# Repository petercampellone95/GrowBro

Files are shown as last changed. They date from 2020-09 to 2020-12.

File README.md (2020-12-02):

# GrowBro

Automated wireless plant growing solution BLE+WiFi(WIP)

To get started with development:

ESP32 IDF Setup (More complicated to build and setup, full functionality: https://docs.espressif.com/projects/esp-idf/en/latest/esp32/get-started/index.html

AND/OR

Arduino ESP32 Setup (Easier, limited functionality, one OS):
  1st: https://randomnerdtutorials.com/installing-the-esp32-board-in-arduino-ide-windows-instructions/
  2nd:https://www.youtube.com/watch?v=gm1N437ng1Y

INSTALL BOTH

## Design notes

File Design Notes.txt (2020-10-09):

PCB Design Notes 
Updated: 9/21/2020

ADC
	Internal ADC limited to 2600mV despite datasheet saying its capable of 3900mV
	Noisy, recommend 0.1uF per ADC input pin
	Might be better to use an external I2C/SPI ADC if higher precision reqd.

PCB Reqs
	Need BT in next rev (different ESP32-S2 PN)
	Smaller Vreg/Cheaper?
	Confirm holes sized for specific screw sizes
	Add 0.1uF on some ADC pins to test	
	Add I2C ports/headers

PCB Fixes
	C1/C5 ref des issue (fixed?)
	C1/C5 silkscreen off of vias
	Replace S1 with a switch that isnt dog shit
	CHIP_EN circuit needs pull-up and possible discharge circuit, reference datasheet
		https://www.espressif.com/sites/default/files/documentation/esp32-wrover_datasheet_en.pdf (page 20-21)
	Get rid of JTAG/USB headers
	Get slide switch for boot mode instead of jumper
	Actually order DC jack or get a smaller power input connector, rated max ~600-800mA
	External ADC, SPI/I2C, 8 CH
	Better noise mitigation strategies, lots of noise on ADC pins in current rev. 
	
PCB Assembly
	Options: Buy reflow oven $200-400
	Use EasyEDA: Have JLCPCB assemble

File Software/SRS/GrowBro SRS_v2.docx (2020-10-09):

# GrowBro

# Software Requirement Specification

1. Introduction
  1.1. The GrowBro ™ is an environment monitoring device that monitors the cultivation of plants. The goal of this system is to provide a reliable and scalable solution capable of supporting both home growers to grow centers. In addition to the main GrowBro ™, there will be a line of single-plant auxiliary wireless sensors that connect to the hub via Bluetooth LE.
2. Software Requirements
  2.1. GrowBro (Hub)
    2.1.1. WiFi Connectivity
      2.1.1.1. The software shall connect to the wireless network via IEEE 802.11 standard (WiFi).
      2.1.1.2. The software shall store the wireless network SSID and WPA key in a safe manor.
      2.1.1.3. The software shall try to automatically reconnect after a wireless network drop.
      2.1.1.4. The software shall transmit data to the external user interfaces via a WiFi connection.
      2.1.1.5. The software shall receive data from the external user interfaces via a WiFi connection.
    2.1.2. Bluetooth Connectivity
      2.1.2.1. The software shall be capable of transmitting data and commands to individual sensors via the Bluetooth LE protocol using the external user interface.
      2.1.2.2. The software shall be capable of receiving messages from the sensors periodically containing telemetry data, status info, and more via the Bluetooth LE protocol.
      2.1.2.3. The sensors will be paired with the GrowBro hub with a unique user specified ID prior to beginning standard operating procedure.
    2.1.3. Functionality
      2.1.3.1. The software shall receive Bluetooth messages from the sensors containing telemetry data, status info, and more every five minutes. The external user interface retains the ability to modify this report interval as desired.
      2.1.3.2. The software shall implement the ability to transmit Bluetooth messages from the GrowBro hub to individual sensors at the request of the user via the external software interfaces.
      2.1.3.3. Upon receipt of sensor data, the software shall push that data to the cloud.
  2.2. Wireless Temperature/Humidity
    2.2.1. Bluetooth Connectivity
      2.2.1.1. The software shall run an internal periodic script that takes temperature and humidity readings on a user specified interval. The user retains the ability to change this interval.
      2.2.1.2. The software shall relay back Bluetooth messages to the main hub that contains temperature and humidity data.
    2.2.2. Sensor Reading
      2.2.2.1. The software shall read the temperature from the sensor.
      2.2.2.2. The software shall read the humidity from the sensor.
  2.3. Wireless Moisture Sensor
    2.3.1. Bluetooth Connectivity
      2.3.1.1. The software shall run an internal periodic script that takes temperature and humidity readings on a user specified interval. The user retains the ability to change this interval.
      2.3.1.2. The software shall relay back Bluetooth messages to the main hub that contains moisture data.
    2.3.2. Sensor Reading
      2.3.2.1. The software shall read the moisture from the software.
  2.4. Phone Application
    2.4.1. Application Functionality
      2.4.1.1. The software shall gather information from the cloud.
      2.4.1.2. The software shall display information to the user.
    2.4.2. GUI
      2.4.2.1. Main Display
        2.4.2.1.1. The software shall display current temperature, humidity, and moisture sensor data as the main focal point.
      2.4.2.2. Tabbed Interface
        2.4.2.2.1. Settings
          2.4.2.2.1.1. The software shall allow the user to change the interface color.
        2.4.2.2.2. Connect/Disconnect
          2.4.2.2.2.1. The software shall add WiFi connection to the hub.
          2.4.2.2.2.2. The software shall change the Wifi connection to the hub.
          2.4.2.2.2.3. The software shall add a new Bluetooth device.
          2.4.2.2.2.4. The software shall remove a Bluetooth device.
          2.4.2.2.2.5. The software shall allow the user to specify a unique ID for each wireless Bluetooth sensor. A unique ID will be created if one is not provided by the user.
        2.4.2.2.3. Charts
          2.4.2.2.3.1. The software shall display 6 month, 1 month, 1 week, and 1 day options.
          2.4.2.2.3.2. Upon selection of options, must query the database on the cloud for the data and neatly print a line chart.
    2.4.3. WiFi Connectivity
      2.4.3.1. The software shall connect to a wireless network.
  2.5. Website Interface
    2.5.1. Application Functionality
      2.5.1.1. The software shall gather information from the cloud.
      2.5.1.2. The software shall display information to the user.
    2.5.2. GUI
      2.5.2.1. The software shall display current temperature, humidity, and moisture levels as the main focal point.

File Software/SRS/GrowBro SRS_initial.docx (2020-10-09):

# GrowBro

# Software Requirement Specification

1. Introduction
  1.1. The GrowBro ™ is an environment monitoring device that monitors the cultivation of plants. The goal of this system is to provide a reliable and scalable solution to cover the bases of home growers to grow centers. In addition to the main GrowBro ™, there will be a line of wireless sensors that connect to the hub via bluetooth.
2. Software Requirements
  2.1. GrowBro (Hub)
    2.1.1. WiFi Connectivity
      2.1.1.1. The software shall connect to the wireless network.
      2.1.1.2. The software shall try to automatically reconnect after a wireless network drop.
      2.1.1.3. The software shall send data to the external user interfaces.
    2.1.2. Bluetooth Connectivity
      2.1.2.1. The software shall send messages to the sensors containing commands for them to wake up and take a reading.
      2.1.2.2. The software shall receive messages from sensors containing sensor data.
    2.1.3. Functionality
      2.1.3.1. The software shall receive sensor data every five minutes.
      2.1.3.2. Upon receipt of sensor data, the software shall push that data to the cloud.
      2.1.3.3. The software shall send bluetooth messages to the sensors every five minutes.
  2.2. Wireless Temperature/Humidity
    2.2.1. Bluetooth Connectivity
      2.2.1.1. The software shall receive bluetooth messages from the main hub that contains information notifying the sensor to take a reading.
      2.2.1.2. The software shall send bluetooth messages to the main hub that contains temperature and humidity data in it.
    2.2.2. Sensor Reading
      2.2.2.1. The software shall read the temperature from the sensor.
      2.2.2.2. The software shall read the humidity from the sensor.
  2.3. Wireless Moisture Sensor
    2.3.1. Bluetooth Connectivity
      2.3.1.1. The software shall receive bluetooth messages from the main hub that contains information notifying the sensor to take a reading.
      2.3.1.2. The software shall send bluetooth messages to the main hub that contains temperature and humidity data in it.
  2.4. Phone Application
    2.4.1. Application Functionality
      2.4.1.1. The software shall gather information from the cloud.
      2.4.1.2. The software shall
    2.4.2. GUI
      2.4.2.1. Main Display
        2.4.2.1.1. The software shall display temperature, humidity, and moisture sensor data as the main focal point.
      2.4.2.2. Tabbed Interface
        2.4.2.2.1. Settings
        2.4.2.2.2. Connect/Disconnect
          2.4.2.2.2.1. The software shall add a new bluetooth device.
          2.4.2.2.2.2. The software shall remove a bluetooth device.
        2.4.2.2.3. Charts
          2.4.2.2.3.1. The software shall display 6 month, 1 month, 1 week, and 1 day options.
          2.4.2.2.3.2. Upon selection of options, must query the database on the cloud for the data and neatly print a line chart.
    2.4.3. WiFi Connectivity
  2.5. Website Interface
    2.5.1. Application Functionality
    2.5.2. GUI

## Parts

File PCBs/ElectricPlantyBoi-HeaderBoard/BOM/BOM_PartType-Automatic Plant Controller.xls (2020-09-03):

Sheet: BOM Report
Bill of Materials |  |  | <Parameter Title not found>
Source Data From: |  | Automatic Plant Controller.PrjPcb
Project: |  | Automatic Plant Controller.PrjPcb
Variant: |  | None
Creation Date: | 9/2/2020 | 10:57:59 PM
Print Date: | 2020-09-02 | 22:58:04
#Column Name Error:Footprint | Comment | #Column Name Error:LibRef | Designator | Description | Quantity
 | 1uF |  | C1 | 0805 1 uF 25 V ±10 % Tolerance X7R SMT Multilayer Ceramic Capacitor | 1
 | Adafruit 2223 Header |  | J1 | GPIO Stacking Header for Pi A+/B+/Pi 2/Pi 3 - Extra-long 2x20 Pins | 1
 | I2C |  | J2 | Board-To-Board Connector, Right Angle, WR-PHD Series, Through Hole, Header, 2, 2.54 mm | 1
 | SPI0 |  | J3 | Board-To-Board Connector, WR-PHD Series, Surface Mount, Header, 6, 2.54 mm, Gold Plated Contacts | 1
 | DHT-1 |  | J4 | THT Vertical Pin Header WR-PHD, Pitch 2.54 mm, Single Row, 3 pins | 1
 | DHT-2 |  | J5 | THT Vertical Pin Header WR-PHD, Pitch 2.54 mm, Single Row, 3 pins | 1
 | DHT-3 |  | J6 | THT Vertical Pin Header WR-PHD, Pitch 2.54 mm, Single Row, 3 pins | 1
 | DHT-4 |  | J7 | THT Vertical Pin Header WR-PHD, Pitch 2.54 mm, Single Row, 3 pins | 1
 | ADC0 |  | J8 | THT Vertical Pin Header WR-PHD, Pitch 2.54 mm, Single Row, 3 pins | 1
 | ADC4 |  | J9 | THT Vertical Pin Header WR-PHD, Pitch 2.54 mm, Single Row, 3 pins | 1
 | ADC1 |  | J10 | THT Vertical Pin Header WR-PHD, Pitch 2.54 mm, Single Row, 3 pins | 1
 | ADC5 |  | J11 | THT Vertical Pin Header WR-PHD, Pitch 2.54 mm, Single Row, 3 pins | 1
 | ADC2 |  | J12 | THT Vertical Pin Header WR-PHD, Pitch 2.54 mm, Single Row, 3 pins | 1
 | ADC6 |  | J13 | THT Vertical Pin Header WR-PHD, Pitch 2.54 mm, Single Row, 3 pins | 1
 | ADC3 |  | J14 | THT Vertical Pin Header WR-PHD, Pitch 2.54 mm, Single Row, 3 pins | 1
 | ADC7 |  | J15 | THT Vertical Pin Header WR-PHD, Pitch 2.54 mm, Single Row, 3 pins | 1
 | 10k |  | R1, R2 | Res, AEC-Q200, Thick Film, 10K, 5%, 0603 | 2
 | 4.7k |  | R3, R4, R5, R6 | Res Thin Film 0603 4.7K Ohm 1% 1/10W ±50ppm/°C Molded SMD SMD Paper T/R | 4
 | MCP3008T-I/SL |  | U1 | 2.7V 4-Channel/8-Channel 10-Bit A/D Converters with SPI Serial Interface, 16-Pin SOIC 150mil, Industrial Temperature, Tape and Reel | 1
 |  |  |  |  | 23
Approved |  | Notes

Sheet: Project Information
Project Full Path | C:\ProgramData\Altium\CircuitMaker {20690677-D4FD-4CB7-A4E9-00349D86A8F9}\Projects\354A3A29-DB29-4F35-BFF8-C48B12B8DA4F\e6ed39b2-680d-427f-b30a-50f9ef953f0c\Automatic Plant Controller.PrjPcb
Project Filename | Automatic Plant Controller.PrjPcb
Variant Name | None
Data-Source Filename | Automatic Plant Controller.PrjPcb
Data-Source Full Path | C:\ProgramData\Altium\CircuitMaker {20690677-D4FD-4CB7-A4E9-00349D86A8F9}\Projects\354A3A29-DB29-4F35-BFF8-C48B12B8DA4F\e6ed39b2-680d-427f-b30a-50f9ef953f0c\Automatic Plant Controller.PrjPcb
Title | <Parameter Title not found>
Total Quantity | 23
Report Time | 10:57:59 PM
Report Date | 9/2/2020
Report Date & Tine | 9/2/2020 10:57:59 PM
Output Name | BOM_PartType
Output Type | BOM_PartType
Output Generator Name | BOM
Output Generator Description | Bill of Materials

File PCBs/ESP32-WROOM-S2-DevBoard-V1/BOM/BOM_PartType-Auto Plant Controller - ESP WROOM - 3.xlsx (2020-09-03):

Comment | Description | Designator | Footprint | LibRef | Quantity | Capacitance | Manufacturer Part Number | PartType | Power Rating | Voltage Rating (DC)
0.1uF | 0402 0.1 uF 25 V ±10% Tolerance X5R SMT Multilayer Ceramic Capacitor | C1 | PCB-5bhg8adqnzhgtf4b63gj-1 | CMP-76b0bfb95be4a977-1 | 1 | 100 nF | TMK105BJ104KV-F | 0.1uF |  | 25.0 V
22uF | LMK212BJ226MG-T TAIYO YU DEN CERAMIC CAPACITOR 22U F 20% 10V X5R 0805 RoHS | C2 | C0805 | CMP-3afbf396deb1e53c-2 | 1 |  |  | 22uF |  | 10.0 V
0.1uF | 0402 0.1 uF 10 V ±10 % Tolerance X5R Surface Mount Multilayer Ceramic Capacitor | C3 | 0402C | CMP-19299680-6 | 1 | 100 nF | GRM155R61A104KA01D | 0.1uF |  | 10.0 V
10uF | CAP CER 10UF 10V 10% X5R 0805 | C4 | PCB-19299738-1 | CMP-19299738-2 | 1 | 1e-05 F | GRM21BR61A106KE19L | 10uF |  | 10.0 V
0.1uF | 0.1uF, ±10%, 50V, X7R, 0805, Multilayer Ceramic Capacitor | C5 | PCB-oygqt4xf3sesynjclq4r-1 | CMP-2758844-5 | 1 | 100 nF | CL21B104KBCNNNC | 0.1uF |  | 50.0 V
3V3_PWR | 1.6 x 0.8 x 0.4 mm (0603) Red 120º Min 11.5mcd Max 28.5mcd SMT LED | D1 | KING-LED0603-25-RED_V | CMP-20cce8f01131ff0b-3 | 1 |  | 19-217/R6C-AL1M2VY/3T | 3V3_PWR
5V_PWR | 1.6 x 0.8 x 0.4 mm (0603) Red 120º Min 11.5mcd Max 28.5mcd SMT LED | D2 | KING-LED0603-25-RED_V | CMP-20cce8f01131ff0b-3 | 1 |  | 19-217/R6C-AL1M2VY/3T | 5V_PWR
PWR_IN | DC Power Connectors DC POWER JACK 2.5MM PIN TYPE 002 | J1 | ADAM-ADC-002-3_V | CMP-3153101-9 | 1 |  | ADC-002-2 | PWR_IN
ADC0 | Conn Unshrouded Header HDR 3 POS 2.54mm Solder ST Thru-Hole | J2 | PCB-xi9jnxfk0tsn3lp09zze-1 | CMP-5821934eb82787e6-1 | 1 |  | 4-103321-5 | ADC0
ADC4 | Conn Unshrouded Header HDR 3 POS 2.54mm Solder ST Thru-Hole | J3 | PCB-xi9jnxfk0tsn3lp09zze-1 | CMP-5821934eb82787e6-1 | 1 |  | 4-103321-5 | ADC4
BOOT_MODE | 2 pin male header straight tht | J4 | Jumper | CMP-08fac3900112d73d-14 | 1 |  |  | BOOT_MODE
ADC1 | Conn Unshrouded Header HDR 3 POS 2.54mm Solder ST Thru-Hole | J5 | PCB-xi9jnxfk0tsn3lp09zze-1 | CMP-5821934eb82787e6-1 | 1 |  | 4-103321-5 | ADC1
ADC5 | Conn Unshrouded Header HDR 3 POS 2.54mm Solder ST Thru-Hole | J6 | PCB-xi9jnxfk0tsn3lp09zze-1 | CMP-5821934eb82787e6-1 | 1 |  | 4-103321-5 | ADC5
ADC2 | Conn Unshrouded Header HDR 3 POS 2.54mm Solder ST Thru-Hole | J7 | PCB-xi9jnxfk0tsn3lp09zze-1 | CMP-5821934eb82787e6-1 | 1 |  | 4-103321-5 | ADC2
ADC6 | Conn Unshrouded Header HDR 3 POS 2.54mm Solder ST Thru-Hole | J8 | PCB-xi9jnxfk0tsn3lp09zze-1 | CMP-5821934eb82787e6-1 | 1 |  | 4-103321-5 | ADC6
ADC3 | Conn Unshrouded Header HDR 3 POS 2.54mm Solder ST Thru-Hole | J9 | PCB-xi9jnxfk0tsn3lp09zze-1 | CMP-5821934eb82787e6-1 | 1 |  | 4-103321-5 | ADC3
ADC7 | Conn Unshrouded Header HDR 3 POS 2.54mm Solder ST Thru-Hole | J10 | PCB-xi9jnxfk0tsn3lp09zze-1 | CMP-5821934eb82787e6-1 | 1 |  | 4-103321-5 | ADC7
UART | Conn Unshrouded Header HDR 4 POS 2.54mm Solder ST Thru-Hole KK?? Bag | J11 | PCB-w7fgx0p37qyww1etoafk-1 | CMP-4df18464dcf59236-2 | 1 |  | 0022032041 | UART
JTAG | Conn Unshrouded Header HDR 4 POS 2.54mm Solder ST Thru-Hole KK?? Bag | J12 | PCB-w7fgx0p37qyww1etoafk-1 | CMP-4df18464dcf59236-2 | 1 |  | 0022032041 | JTAG
DHT1 | Conn Unshrouded Header HDR 3 POS 2.54mm Solder ST Thru-Hole | J13 | PCB-xi9jnxfk0tsn3lp09zze-1 | CMP-5821934eb82787e6-1 | 1 |  | 4-103321-5 | DHT1
DHT3 | Conn Unshrouded Header HDR 3 POS 2.54mm Solder ST Thru-Hole | J14 | PCB-xi9jnxfk0tsn3lp09zze-1 | CMP-5821934eb82787e6-1 | 1 |  | 4-103321-5 | DHT3
DHT2 | Conn Unshrouded Header HDR 3 POS 2.54mm Solder ST Thru-Hole | J15 | PCB-xi9jnxfk0tsn3lp09zze-1 | CMP-5821934eb82787e6-1 | 1 |  | 4-103321-5 | DHT2
DHT4 | Conn Unshrouded Header HDR 3 POS 2.54mm Solder ST Thru-Hole | J16 | PCB-xi9jnxfk0tsn3lp09zze-1 | CMP-5821934eb82787e6-1 | 1 |  | 4-103321-5 | DHT4
USB_OTG | 2 pin male header straight tht | J17 | Jumper | CMP-08fac3900112d73d-14 | 1 |  |  | USB_OTG
10k | Res, AEC-Q200, Thick Film, 10K, 5%, 0603 | R1, R4 | PCB-urbe6pl2f36u5sj9z9e0-1 | CMP-1974d512ef63c6b3-1 | 2 |  | CRGCQ0603J10K | 10k
0 | RC Series 0402 0.063 W 0 Ohms Jumper Surface Mount Thick Film Chip Resistor | R2, R3 | PCB-azzhouwj1h0sqqpj65ny-1 | CMP-13527731-11 | 2 |  |  | 0
620 | Thick Film Resistors - SMD 0402 620ohms 5% Tol | R5 | RESC1005X40X25NL05T05 | CMP-3676372-2 | 1 |  | ERJ-2GEJ621X | 620 | 0.1 W | 50.0 V
1k | RES SMD 1K OHM 5% 1/16W 0402 | R6 | RESC1005X40X25NL05T05 | CMP-1903935-2 | 1 |  | CRCW04021K00JNTD | 1k | 0.063 W | 50.0 V
CHIP_EN | Switch Tactile Spst-No 0.02a 15v | S1 | PCB-xzcf6rj7v3ysitq80b7l-1 | CMP-32abff024869ed6c-2 | 1 |  |  | CHIP_EN
ESP32-S2-WROOM | SMD Module ESP32-S2-WROOM | U1 | PCBComponent_1 | CMP-dacd15a1cbe3050a-2 | 1 |  |  | ESP32-S2-WROOM
LD1117S33CTR | Fixed Low Drop Positive Voltage Regulator, 3.3V, 4-Pin SOT-223, Tape and Reel | U2 | SOT-223_N | CMP-1170392-2 | 1 |  | LD1117S33CTR | LD1117S33CTR

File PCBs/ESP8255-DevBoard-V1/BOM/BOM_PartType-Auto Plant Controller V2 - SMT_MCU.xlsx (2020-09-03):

Comment | Description | Designator | Footprint | LibRef | Manufacturer Part Number | Quantity
WIFI_ANTENNA | Meandered Inverted-F Antenna | A1 | PCB-wx81mnio3p969u8b8u4u-1 | CMP-nvfputv9e4hvqhxbgt68-5 |  | 1
1uF | 0805 1 uF 25 V ±10 % Tolerance X7R SMT Multilayer Ceramic Capacitor | C1, C6, C10 | C0805 | CMP-77c3bc4dc880a804-3 | CC0805KKX7R8BB105 | 3
15pF | 15pF ±1% 50V C0G, NP0 Ceramic Capacitor -55°C ~ 125°C Surface Mount, MLCC 0402 (1005 Metric) 0.039" L x 0.020" W (1.00mm x 0.50mm) | C2, C3 | PCB-98fz84kwkqgd8opjlb99-1 | CMP-a0ab688c22207f6c-1 | GRM1555C1H150FA01D | 2
2.4pF | CAP CER 2.4PF 50V NP0 0402 | C4 | CAPC1005X55X25ML05T10 | CMP-119517-2 | GJM1555C1H2R4CB01D | 1
3pF | Multilayer Ceramic Capacitors MLCC - SMD/SMT 0402 3.0pF 50volts C0G +/-0.25pF | C5 | CAPC1005X55X25ML05T10 | CMP-2512733-2 | GRM1555C1H3R0CA01D | 1
0.47uF | CL10 Series 0.47 uF 16 V ±10 % Tolerance X7R SMT Multilayer Ceramic Capacitor | C7 | CAPC1608X90X35ML15T15 | CMP-55ff9c78cd6f8a38-1 |  | 1
10uF | Cap Ceramic 10uF 25V X5R 10% SMD 0805 85C Paper T/R | C8 | PCB-3l8viaoeo84t9gm70k7i-1 | CMP-5e7a9647d7d381bd-6 | TMK212BBJ106KG-T | 1
0.1uF | 0.1uF, ±10%, 50V, X7R, 0805, Multilayer Ceramic Capacitor | C9, C11, C12 | PCB-oygqt4xf3sesynjclq4r-1 | CMP-2758844-5 | CL21B104KBCNNNC | 3
3V3_PWR | Blue 1.6 x 0.8 x 0.3 mm 130° Clear 180 mcd 3.8 V Surface Mount LED | D1 | PCB-1544848-1 | CMP-1f66d74e5acac0a1-1 | LTST-C194TBKT | 1
5V_PWR | LED; SMD; 0603; red; 18-54mcd; 1.6x0.8x0.55mm; 130°; 2÷2.4V; 20mA | D2 | DIOM1608X06N | CMP-1544848-9 |  | 1
PWR_IN | DC Power Connectors DC POWER JACK 2.5MM PIN TYPE 002 | J1 | ADAM-ADC-002-3_V | CMP-3153101-9 | ADC-002-2 | 1
UART | Conn; Rect; UnshroudedHdr; 6Cnts; ThruHole; BergStik; 2.54mmPin-Spng; Vert; 1-Row | J2 | PCB-di8nzhz8ya7afv8i1myi-1 | CMP-ea272149382c35e0-4 |  | 1
RST | 2 pin male header straight tht | J3 | Jumper | CMP-08fac3900112d73d-14 |  | 1
BOOT_MODE | THT Vertical Pin Header WR-PHD, Pitch 2.54 mm, Single Row, 3 pins | J4 | PCB-s0hfil65plaomi4ibvcw-1 | CMP-8a90426ffa175557-34 |  | 1
DHT1 | THT Vertical Pin Header WR-PHD, Pitch 2.54 mm, Single Row, 3 pins | J5 | PCB-s0hfil65plaomi4ibvcw-1 | CMP-8a90426ffa175557-34 |  | 1
DHT2 | THT Vertical Pin Header WR-PHD, Pitch 2.54 mm, Single Row, 3 pins | J6 | PCB-s0hfil65plaomi4ibvcw-1 | CMP-8a90426ffa175557-34 |  | 1
DHT3 | THT Vertical Pin Header WR-PHD, Pitch 2.54 mm, Single Row, 3 pins | J7 | PCB-s0hfil65plaomi4ibvcw-1 | CMP-8a90426ffa175557-34 |  | 1
DHT4 | THT Vertical Pin Header WR-PHD, Pitch 2.54 mm, Single Row, 3 pins | J8 | PCB-s0hfil65plaomi4ibvcw-1 | CMP-8a90426ffa175557-34 |  | 1
ADC_0 | THT Vertical Pin Header WR-PHD, Pitch 2.54 mm, Single Row, 3 pins | J9 | PCB-s0hfil65plaomi4ibvcw-1 | CMP-8a90426ffa175557-34 |  | 1
ADC_1 | THT Vertical Pin Header WR-PHD, Pitch 2.54 mm, Single Row, 3 pins | J10 | PCB-s0hfil65plaomi4ibvcw-1 | CMP-8a90426ffa175557-34 |  | 1
ADC_2 | THT Vertical Pin Header WR-PHD, Pitch 2.54 mm, Single Row, 3 pins | J11 | PCB-s0hfil65plaomi4ibvcw-1 | CMP-8a90426ffa175557-34 |  | 1
ADC_3 | THT Vertical Pin Header WR-PHD, Pitch 2.54 mm, Single Row, 3 pins | J12 | PCB-s0hfil65plaomi4ibvcw-1 | CMP-8a90426ffa175557-34 |  | 1
ADC_4 | THT Vertical Pin Header WR-PHD, Pitch 2.54 mm, Single Row, 3 pins | J13 | PCB-s0hfil65plaomi4ibvcw-1 | CMP-8a90426ffa175557-34 |  | 1
ADC_5 | THT Vertical Pin Header WR-PHD, Pitch 2.54 mm, Single Row, 3 pins | J14 | PCB-s0hfil65plaomi4ibvcw-1 | CMP-8a90426ffa175557-34 |  | 1
ADC_6 | THT Vertical Pin Header WR-PHD, Pitch 2.54 mm, Single Row, 3 pins | J15 | PCB-s0hfil65plaomi4ibvcw-1 | CMP-8a90426ffa175557-34 |  | 1
ADC_7 | THT Vertical Pin Header WR-PHD, Pitch 2.54 mm, Single Row, 3 pins | J16 | PCB-s0hfil65plaomi4ibvcw-1 | CMP-8a90426ffa175557-34 |  | 1
2.2nH | Inductor RF Chip Thin Film 2.2nH 0.1nH 500MHz 14Q-Factor 600mA 150mOhm DCR 0201 Paper T/R | L1 | PCB-vg5vda2wcniu3fh2gltx-1 | CMP-80494860bc425f8e-1 | LQP03TN2N2B02D | 1
4.3nH | Surface Mount High Frequency Inductor, LQW15AN Series, 4.3 nH, 0.1nH, 0402 [1005 Metric], 10 GHz | L2 | PCB-vetezry5jn2cqs6s1af8-1 | CMP-e5012c7543d03ac6-1 | LQW15AN4N3B00D | 1
12k | Res Thick Film 0603 12K Ohm 1% 0.1W(1/10W) ±100ppm/C Molded SMD Automotive Paper T/R | R1 | RESC1609X50X30LL10T20 | CMP-1857522-10 |  | 1
180 | Thick Film Resistors - SMD 1/8watts 180ohms 1% | R2, R3 | RESC2013X60X30NL20T20 | CMP-3657049-2 | RK73H2ATTD1800F | 2
10k | Res, AEC-Q200, Thick Film, 10K, 5%, 0603 | R4, R5, R6, R8, R10 | PCB-urbe6pl2f36u5sj9z9e0-1 | CMP-1974d512ef63c6b3-1 | CRGCQ0603J10K | 5
499 | Res Thick Film 0603 499 Ohm 1% 1/10W ±100ppm/C Molded SMD Paper T/R | R7 | RESC1609X50X30ML10T20 | CMP-3835606-2 | CRCW0603499RFKEA | 1
4.7k | Res Thick Film 0603 4.7K Ohm 5% 0.1W(1/10W) ±200ppm/C Molded SMD Automotive Punched Paper T/R | R9 | RESC1608X55X30ML20T10 | CMP-2823469-2 | RK73B1JTTD472J | 1
150k | Thick Film Resistors - SMD 0603 150Kohms 1% Tol | R11 | RESC1608X55X30LL15T15 | CMP-3654711-2 | ERJ-3EKF1503V | 1
75k | Thick Film Resistors - SMD 0603 75Kohms 1% Tol | R12 | RESC1608X55X30LL15T15 | CMP-3654871-2 | ERJ-3EKF7502V | 1
2.2k | Res, AEC-Q200, Thick Film, 2K2, 5%, 0603 | R13 | PCB-2t5lv6a742zfbi3344hk-1 | CMP-ce770211389311b0-1 | CRGCQ0603J2K2 | 1
CHIP_EN | Switch Tactile Spst-No 0.02a 15v | S1 | PCB-xzcf6rj7v3ysitq80b7l-1 | CMP-32abff024869ed6c-2 |  | 1
ESP8285H16 | RF Transceiver 64QAM/BPSK/CCK/DSSS/OFDM 2.7V to 3.6V 2400MHz to 2483.5MHz 32-Pin QFN | U1 | PCB-1fh2hqe1x48mh17li7t6-1 | CMP-265ae9019d32f99d-2 | ESP8285H16 | 1
SN74LV4051APWR | 5-V, 8: 1, 1-channel general-purpose analog multiplexer 16-TSSOP -40 to 85 | U2 | PCB-s2tlwx05pg4l7j3eq4ax-1 | CMP-2f9ae6973f1af05d-4 | SN74LV4051APWR | 1
TLV75533PDBVR | 500-mA low-IQ small-size low-dropout (LDO) regulator 5-SOT-23 -40 to 125 | U3 | PCB-9xapb279xxlk04njnstk-1 | CMP-a508697234f37acf-1 | TLV75533PDBVR | 1
26MHz | Crystal 26MHz ±10ppm (Tol) ±10ppm (Stability) 10pF FUND 50Ohm 4-Pin CSMD T/R | X1 | PCB-1zhjv6m1p58g6yr6i7sc-1 | CMP-932d5a23796e4cea-3 | ABM8-26.000MHZ-10-1-U-T | 1

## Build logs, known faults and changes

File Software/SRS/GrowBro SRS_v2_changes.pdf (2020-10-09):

# GrowBro

## Software Requirement Specification

1. Introduction
1.1. The GrowBro ™ is an environment monitoring device that monitors the cultivation of plants. The goal of this system is to provide a reliable and scalable solution capableto cover the bases of supporting both home growers to grow centers. In addition to the main GrowBro ™, there will be a line of single-plant auxiliary wireless sensors that connect to the hub via Bbluetooth LE.
2. Software Requirements
2.1. GrowBro (Hub)
2.1.1. WiFi Connectivity
2.1.1.1. The software shall connect to the wireless network via IEEE 802.11 standard (WiFi)k.
2.1.1.2. The software shall try to automatically reconnect after a wireless network drop.
2.1.1.3. The software shall transmitsend data to the external user interfaces via a WiFi connection..
2.1.1.3.2.1.1.4. The software shall receive data from the external user interfaces via a WiFi connection.
2.1.2. Bluetooth Connectivity
2.1.2.2.1.2.1. The software shall be capable of transmitting data and commands to individual sensors via the Bluetooth LE protocol using the external user interface.
2.1.2.2. The software shall be capable of shall send messages to the sensors containing commands for them to wake up and take a reading.receiving messages from the sensors periodically containing telemetry data, status info, and more via the Bluetooth LE protocol.
2.1.2.1.2.1.2.3. The sensors will be paired with the GrowBro hub with a unique user specified ID prior to beginning standard operating procedure.
2.1.3.0. The software shall receive messages from sensors containing sensor data.
2.1.4.2.1.3. Functionality
2.1.3.1. The software shall receive Bluetooth messages from the sensors containing telemetry data, status info, and more every five minutes. The external user interface retains the ability to modify this report interval as desired.
2.1.3.2. The software shall implement the ability to transmit Bluetooth messages from the GrowBro hub to individual sensors at the request of the user via the external software interfaces.
2.1.4.1. The software shall receive sensor data every five minutes.

Formatted

2.1.4.2. Upon receipt of sensor data, the software shall push that data to the cloud..
2.1.3.3.
The software shall send bluetooth messages to the sensors every five minutes.

2.1.4.3.
2.2. Wireless Temperature/Humidity
2.2.1. Bluetooth Connectivity
2.2.1.1. The software run an internal periodic script that takes temperature and humidity readings on a user specified interval. The user retains the ability to change this interval.shall receive bluetooth messages from the main hub that contains information notifying the sensor to take a reading.
2.2.1.2. The software shall send relay back Bbluetooth messages to the main hub that contains temperature and humidity data in it.data.
2.2.2. Sensor Reading
2.2.2.1. The software shall read the temperature from the sensor.
2.2.2.2. The software shall read the humidity from the sensor.
2.3. Wireless Moisture Sensor
2.3.1. Bluetooth Connectivity
2.3.1.1. The software shall run an internal periodic script that takes temperature and humidity readings on a user specified interval. The user retains the ability to change this interval.
2.3.1.2. The software shall relay back Bluetooth messages to the main hub that contains moisture data.
2.4.0.0. The software shall receive bluetooth messages from the main hub that contains information notifying the sensor to take a reading.
2.5.0.0. The software shall send bluetooth messages to the main hub that contains temperature and humidity data in it.
2.6.2.4. Phone Application
2.6.1.2.4.1. Application Functionality
2.6.1.1.2.4.1.1. The software shall gather information from the cloud.
2.6.1.2.2.4.1.2. The software shall
2.6.2.2.4.2. GUI
2.6.2.1.2.4.2.1. Main Display
2.6.2.1.1.2.4.2.1.1. The software shall display temperature, humidity, and moisture sensor data as the main focal point.

Formatted: Indent: Left: 2", No bullets or numbering

2.6.2.2.2.4.2.2. Tabbed Interface
2.6.2.2.1.2.4.2.2.1. Settings
2.6.2.2.2.2.4.2.2.2. Connect/Disconnect
2.6.2.2.2.1.2.4.2.2.2.1. The software shall add a new Bbluetooth device.
2.6.2.2.2.2.2.4.2.2.2.2. The software shall remove a Bbluetooth device.
2.6.2.2.2.3.2.4.2.2.2.3. The software shall allow the user to specify a unique ID for each wireless Bluetooth sensor. A unique ID will be created if one is not provided by the user.
2.6.2.2.3.2.4.2.2.3. Charts
2.6.2.2.3.1.2.4.2.2.3.1. The software shall display 6 month, 1 month, 1 week, and 1 day options.
2.6.2.2.3.2.2.4.2.2.3.2. Upon selection of options, must query the database on the cloud for the data and neatly print a line chart.
2.6.2.2.4.2.4.2.2.4.
2.6.3.2.4.3. WiFi Connectivity
2.7.2.5. Website Interface
2.7.1.2.5.1. Application Functionality
2.7.2.2.5.2. GUI

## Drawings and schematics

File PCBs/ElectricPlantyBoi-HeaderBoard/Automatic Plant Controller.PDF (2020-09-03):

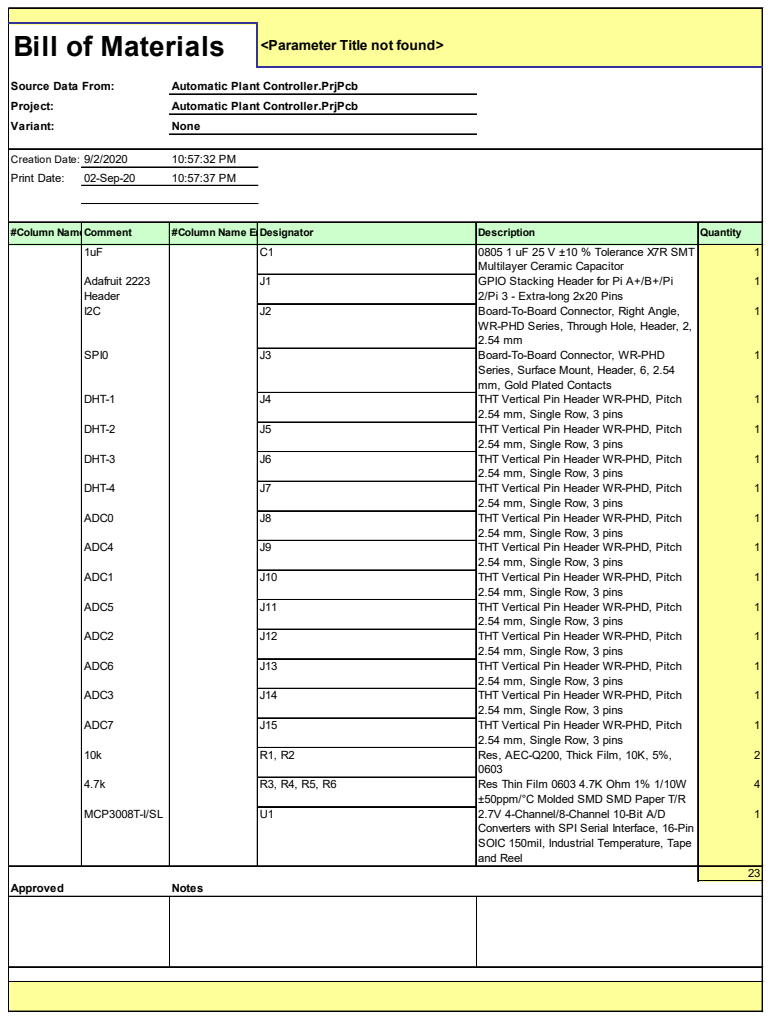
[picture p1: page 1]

#Column NameComment | #Column Name ErDesignator | Description | Quantity

2/Pi 3 - Extra-long 2x20 Pins

WR-PHD Series, Through Hole, Header, 2,

Series, Surface Mount, Header, 6, 2.54
mm, Gold Plated Contacts

2.54 mm, Single Row, 3 pins

±50ppm/°C Molded SMD SMD Paper T/R

Converters with SPI Serial Interface, 16-Pin
SOIC 150mil, Industrial Temperature, Tape
and Reel

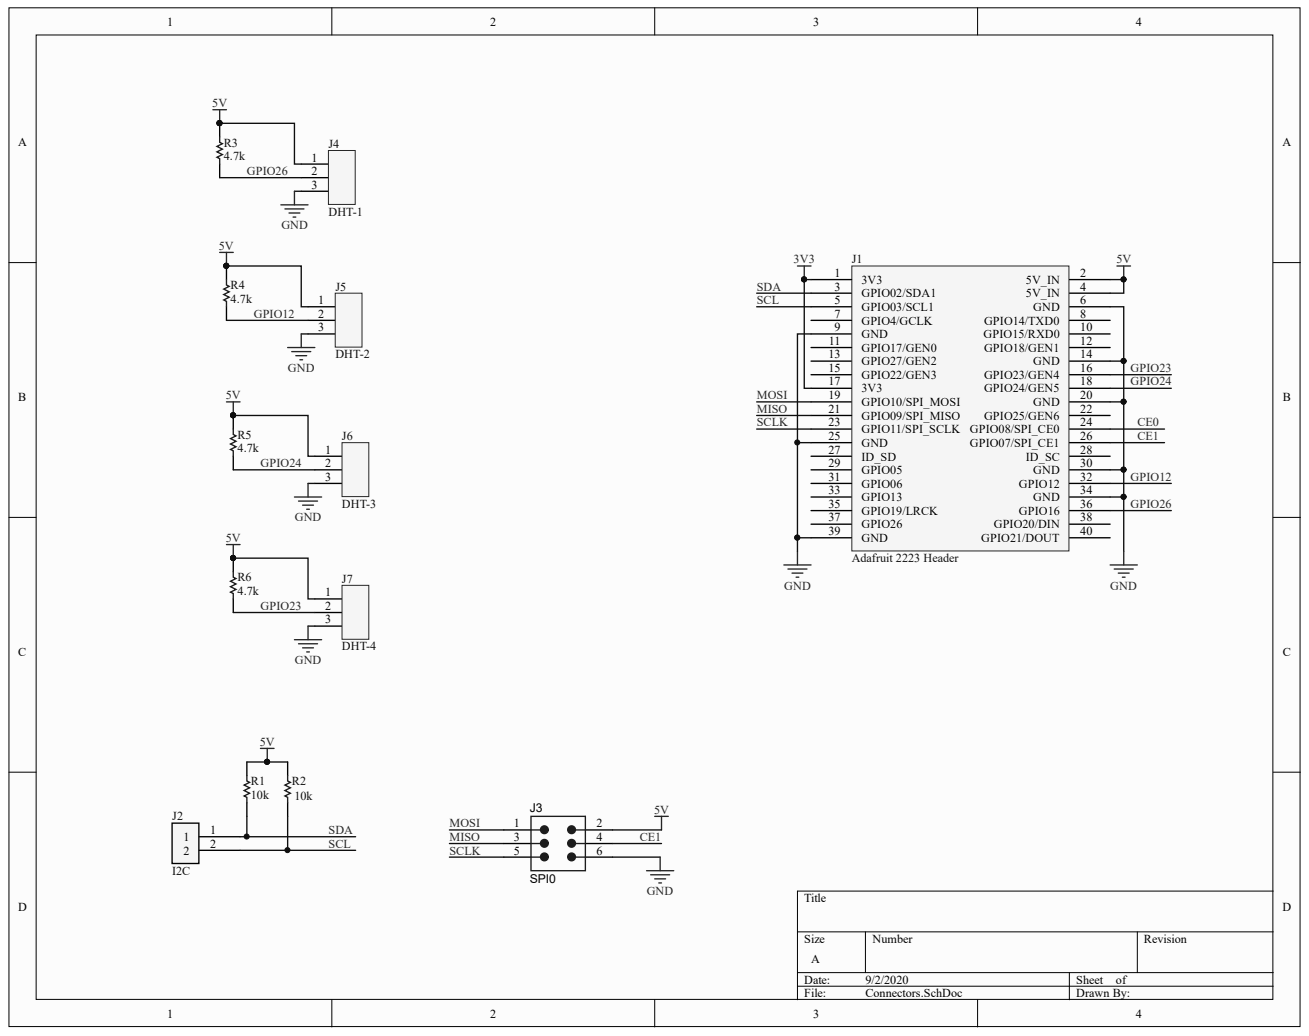
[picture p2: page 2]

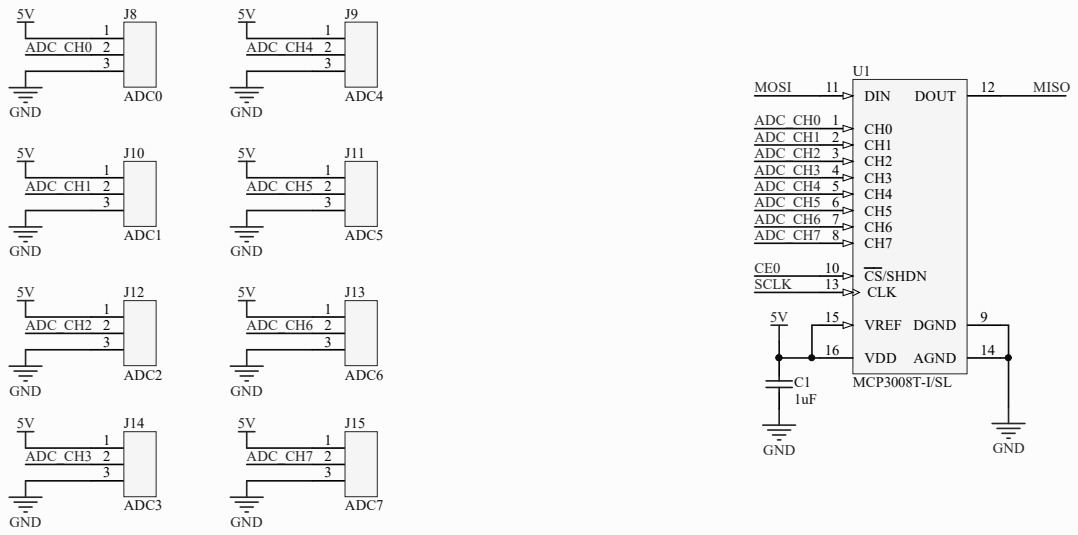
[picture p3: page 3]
VREF 15; DIN 11; 5V GND; J10 ADC1; J12 ADC2; J14 ADC3; J13 ADC6; J15 ADC7; 5V GNDADC_CH

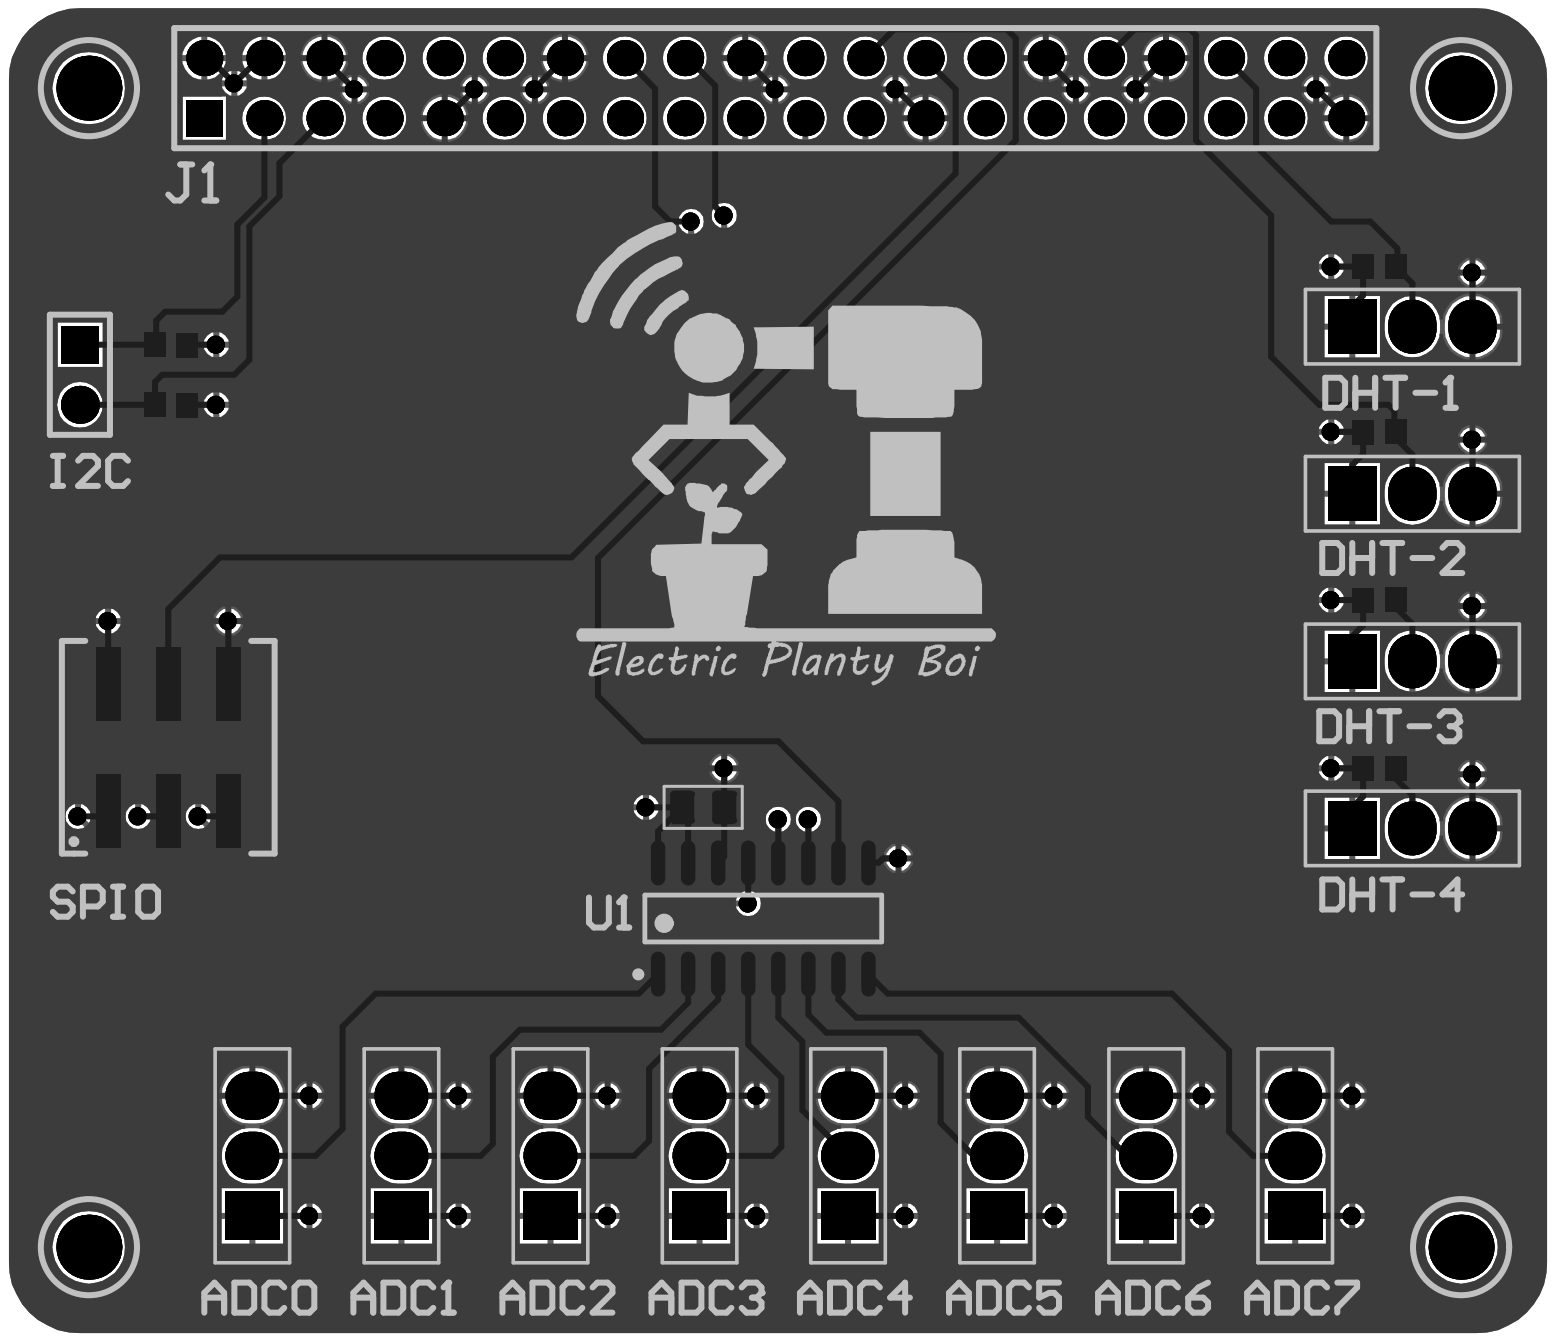
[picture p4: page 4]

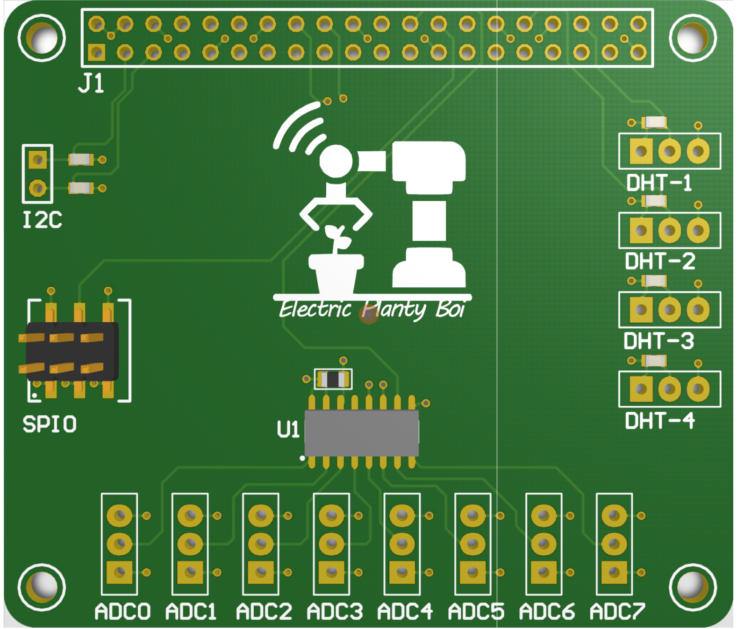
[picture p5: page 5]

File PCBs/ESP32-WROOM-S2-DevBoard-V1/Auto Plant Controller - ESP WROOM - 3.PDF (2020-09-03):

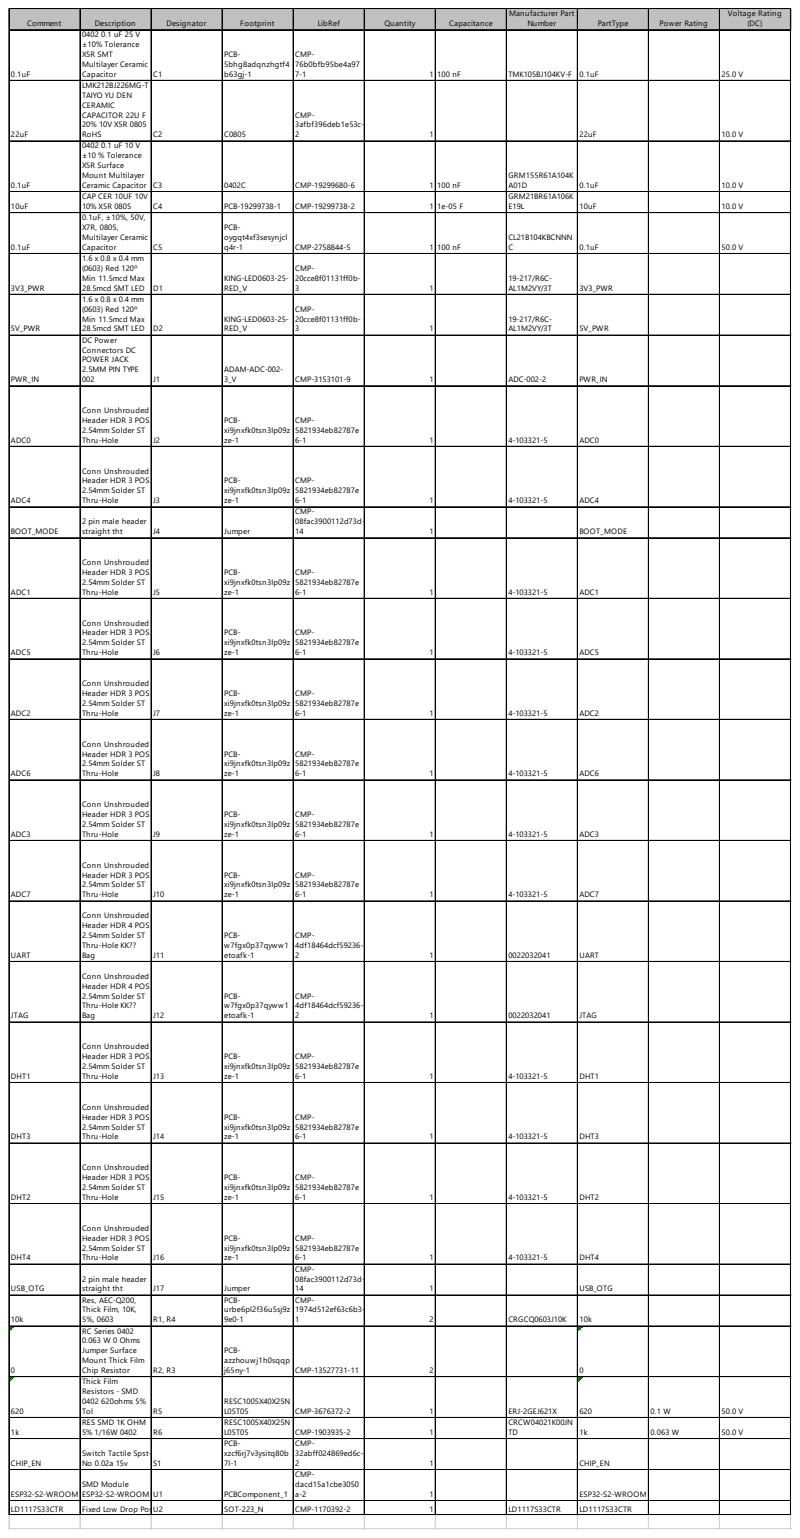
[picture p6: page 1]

Comment | Description | Designator | Footprint | LibRef | Quantity | Capacitance | Manufacturer Part Number | PartType | Power Rating | Voltage Rating (DC)

0.1uF | 0402 0.1 uF 25 V ±10% Tolerance X5R SMT Multilayer Ceramic Capacitor | C1 | PCB-5bhg8adqnzhgtf4 b63gj-1 | CMP-76b0bfb95be4a97 7-1 | 1 | 100 nF | TMK105BJ104KV-F | 0.1uF | | 25.0 V

22uF | LMK212BJ226MG-T TAIYO YU DEN CERAMIC CAPACITOR 22U F 20% 10V X5R 0805 RoHS | C2 | C0805 | CMP-3afbf396deb1e53c-2 | 1 | | | 22uF | | 10.0 V

0.1uF | 0402 0.1 uF 10 V ±10 % Tolerance X5R Surface Mount Multilayer Ceramic Capacitor | C3 | 0402C | CMP-19299680-6 | 1 | 100 nF | GRM155R61A104K A01D | 0.1uF | | 10.0 V

10uF | CAP CER 10UF 10V 10% X5R 0805 | C4 | PCB-19299738-1 | CMP-19299738-2 | 1 | 1e-05 F | GRM21BR61A106K E19L | 10uF | | 10.0 V

0.1uF | 0.1uF, ±10%, 50V, X7R, 0805, Multilayer Ceramic Capacitor | C5 | PCB-oygqt4xf3sesynjcl q4r-1 | CMP-2758844-5 | 1 | 100 nF | CL21B104KBCNNN C | 0.1uF | | 50.0 V

3V3_PWR | 1.6 x 0.8 x 0.4 mm (0603) Red 120º Min 11.5mcd Max 28.5mcd SMT LED | D1 | KING-LED0603-25-RED_V | CMP-20cce8f01131ff0b-3 | 1 | | 19-217/R6C-AL1M2VY/3T | 3V3_PWR

5V_PWR | 1.6 x 0.8 x 0.4 mm (0603) Red 120º Min 11.5mcd Max 28.5mcd SMT LED | D2 | KING-LED0603-25-RED_V | CMP-20cce8f01131ff0b-3 | 1 | | 19-217/R6C-AL1M2VY/3T | 5V_PWR

PWR_IN | DC Power Connectors DC POWER JACK 2.5MM PIN TYPE 002 | J1 | ADAM-ADC-002-3_V | CMP-3153101-9 | 1 | | ADC-002-2 | PWR_IN

ADC0 | Conn Unshrouded Header HDR 3 POS 2.54mm Solder ST Thru-Hole | J2 | PCB-xi9jnxfk0tsn3lp09z ze-1 | CMP-5821934eb82787e 6-1 | 1 | | 4-103321-5 | ADC0

ADC4 | Conn Unshrouded Header HDR 3 POS 2.54mm Solder ST Thru-Hole | J3 | PCB-xi9jnxfk0tsn3lp09z ze-1 | CMP-5821934eb82787e 6-1 | 1 | | 4-103321-5 | ADC4

BOOT_MODE | 2 pin male header straight tht | J4 | Jumper | CMP-08fac3900112d73d-14 | 1 | | | BOOT_MODE

ADC1 | Conn Unshrouded Header HDR 3 POS 2.54mm Solder ST Thru-Hole | J5 | PCB-xi9jnxfk0tsn3lp09z ze-1 | CMP-5821934eb82787e 6-1 | 1 | | 4-103321-5 | ADC1

ADC5 | Conn Unshrouded Header HDR 3 POS 2.54mm Solder ST Thru-Hole | J6 | PCB-xi9jnxfk0tsn3lp09z ze-1 | CMP-5821934eb82787e 6-1 | 1 | | 4-103321-5 | ADC5

ADC2 | Conn Unshrouded Header HDR 3 POS 2.54mm Solder ST Thru-Hole | J7 | PCB-xi9jnxfk0tsn3lp09z ze-1 | CMP-5821934eb82787e 6-1 | 1 | | 4-103321-5 | ADC2

ADC6 | Conn Unshrouded Header HDR 3 POS 2.54mm Solder ST Thru-Hole | J8 | PCB-xi9jnxfk0tsn3lp09z ze-1 | CMP-5821934eb82787e 6-1 | 1 | | 4-103321-5 | ADC6

ADC3 | Conn Unshrouded Header HDR 3 POS 2.54mm Solder ST Thru-Hole | J9 | PCB-xi9jnxfk0tsn3lp09z ze-1 | CMP-5821934eb82787e 6-1 | 1 | | 4-103321-5 | ADC3

ADC7 | Conn Unshrouded Header HDR 3 POS 2.54mm Solder ST Thru-Hole | J10 | PCB-xi9jnxfk0tsn3lp09z ze-1 | CMP-5821934eb82787e 6-1 | 1 | | 4-103321-5 | ADC7

UART | Conn Unshrouded Header HDR 4 POS 2.54mm Solder ST Thru-Hole KK?? Bag | J11 | PCB-w7fgx0p37qyww1 etoafk-1 | CMP-4df18464dcf59236-2 | 1 | | 0022032041 | UART

JTAG | Conn Unshrouded Header HDR 4 POS 2.54mm Solder ST Thru-Hole KK?? Bag | J12 | PCB-w7fgx0p37qyww1 etoafk-1 | CMP-4df18464dcf59236-2 | 1 | | 0022032041 | JTAG

DHT1 | Conn Unshrouded Header HDR 3 POS 2.54mm Solder ST Thru-Hole | J13 | PCB-xi9jnxfk0tsn3lp09z ze-1 | CMP-5821934eb82787e 6-1 | 1 | | 4-103321-5 | DHT1

DHT3 | Conn Unshrouded Header HDR 3 POS 2.54mm Solder ST Thru-Hole | J14 | PCB-xi9jnxfk0tsn3lp09z ze-1 | CMP-5821934eb82787e 6-1 | 1 | | 4-103321-5 | DHT3

DHT2 | Conn Unshrouded Header HDR 3 POS 2.54mm Solder ST Thru-Hole | J15 | PCB-xi9jnxfk0tsn3lp09z ze-1 | CMP-5821934eb82787e 6-1 | 1 | | 4-103321-5 | DHT2

DHT4 | Conn Unshrouded Header HDR 3 POS 2.54mm Solder ST Thru-Hole | J16 | PCB-xi9jnxfk0tsn3lp09z ze-1 | CMP-5821934eb82787e 6-1 | 1 | | 4-103321-5 | DHT4

USB_OTG | 2 pin male header straight tht | J17 | Jumper | CMP-08fac3900112d73d-14 | 1 | | | USB_OTG

10k | Res, AEC-Q200, Thick Film, 10K, 5%, 0603 | R1, R4 | PCB-urbe6pl2f36u5sj9z 9e0-1 | CMP-1974d512ef63c6b3-1 | 2 | | CRGCQ0603J10K | 10k

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

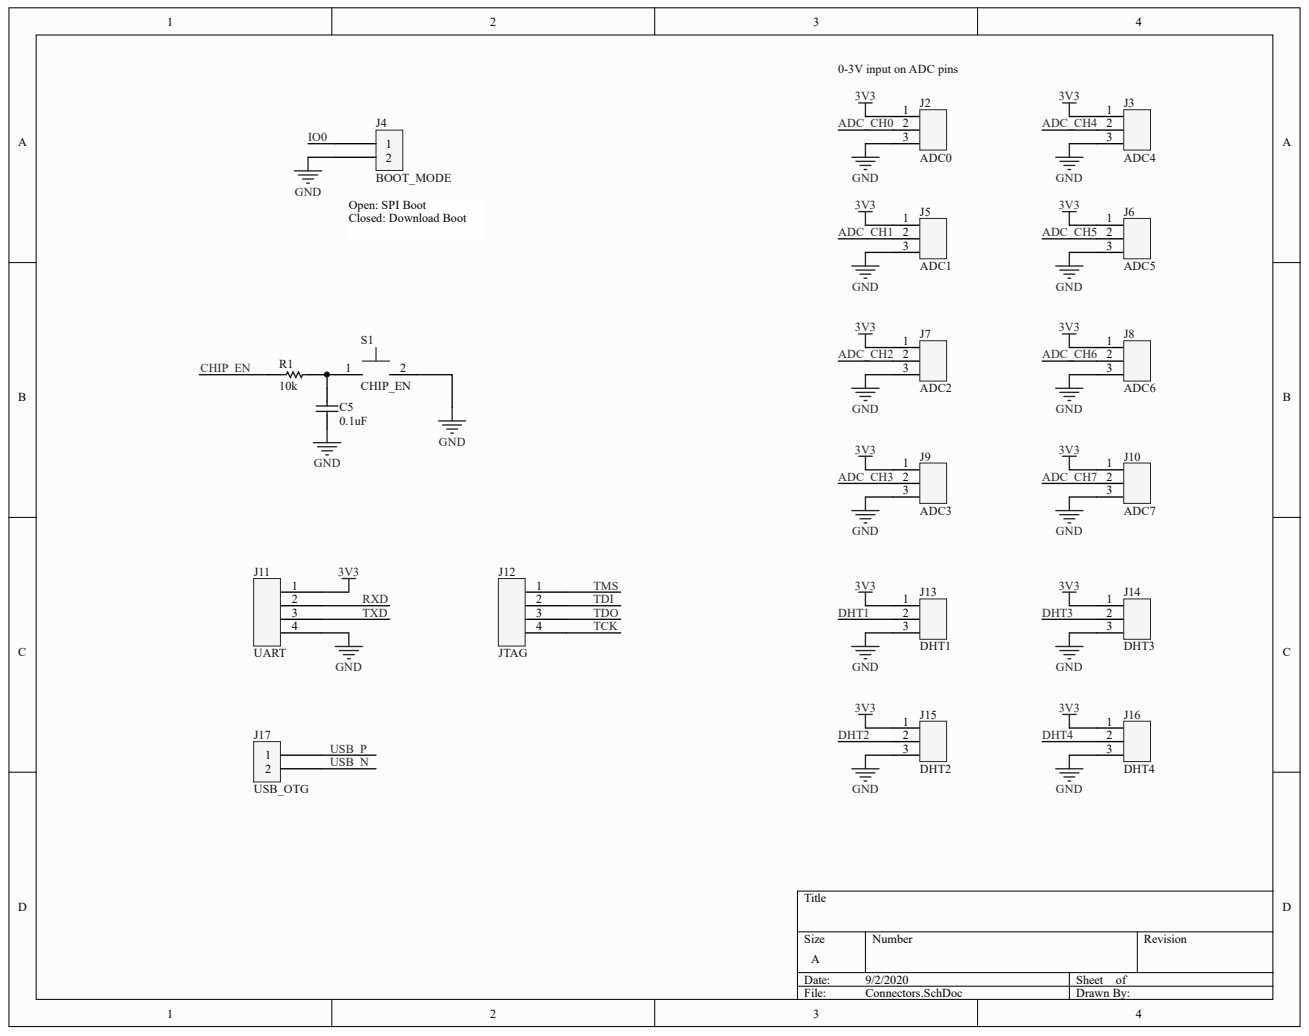
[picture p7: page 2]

0-3V input on ADC pins

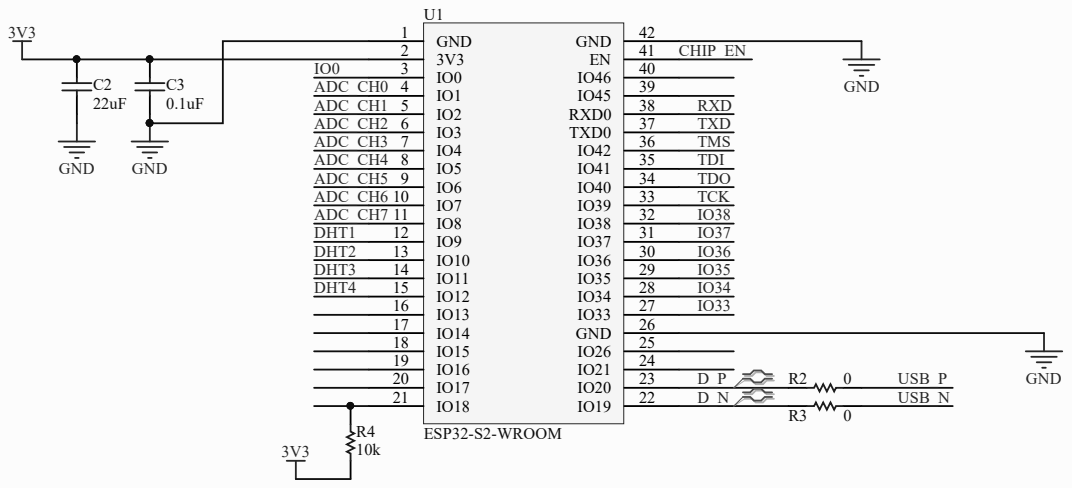
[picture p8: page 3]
25 GND; 36 TXD0; 37 RXD0; 41 GND; 42 U1 ESP32-S2-WROOM

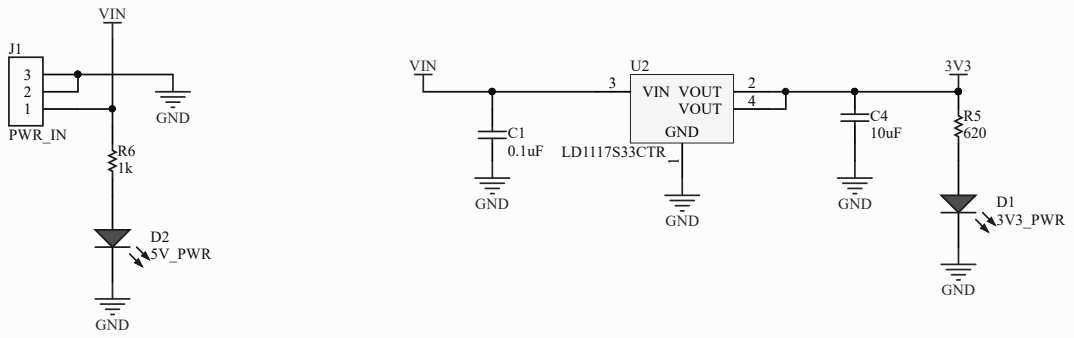
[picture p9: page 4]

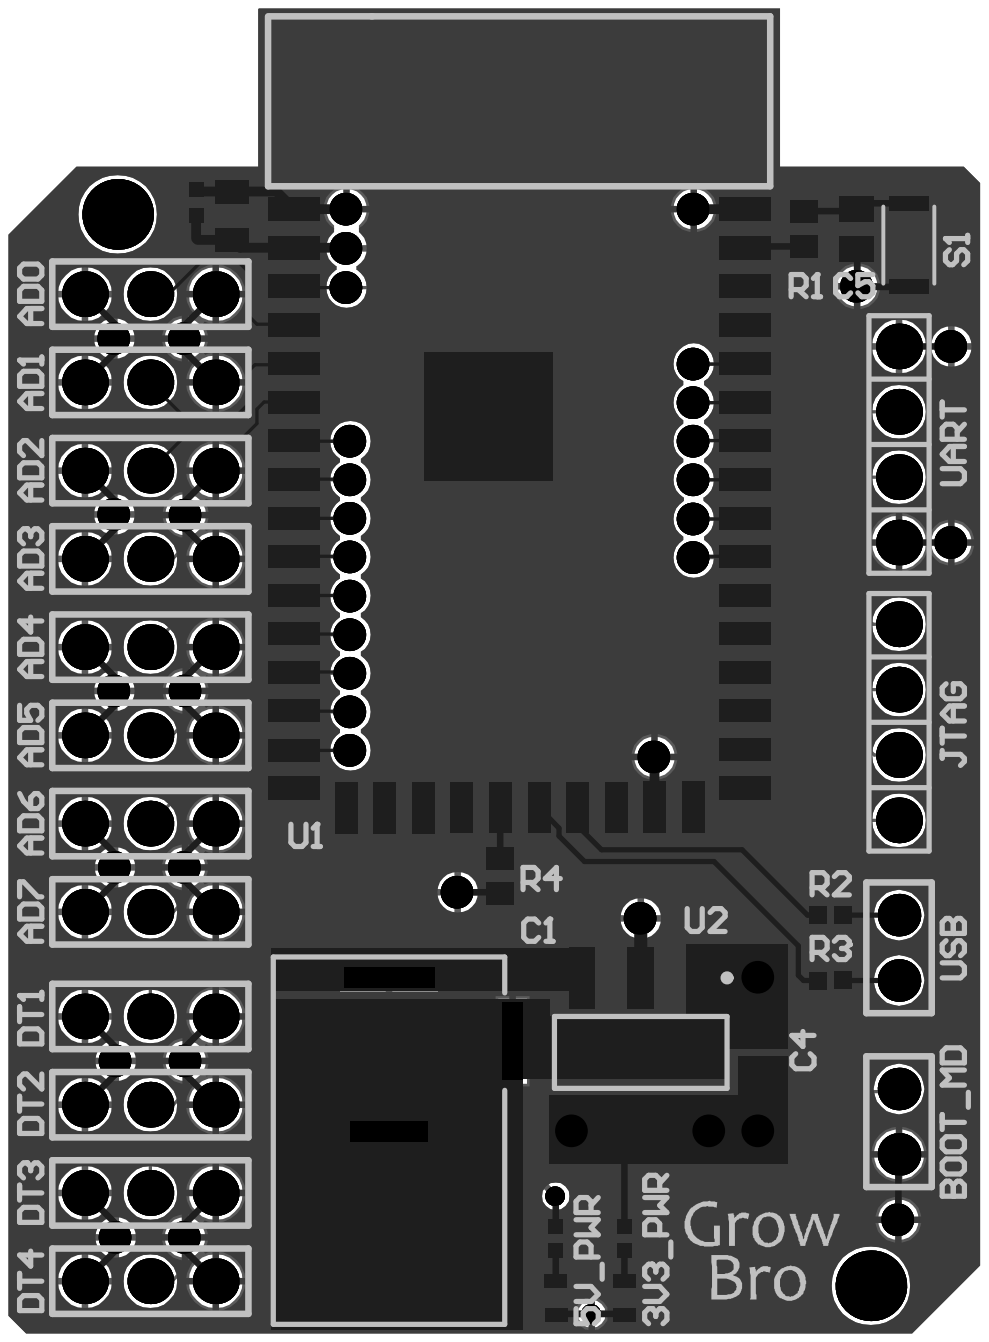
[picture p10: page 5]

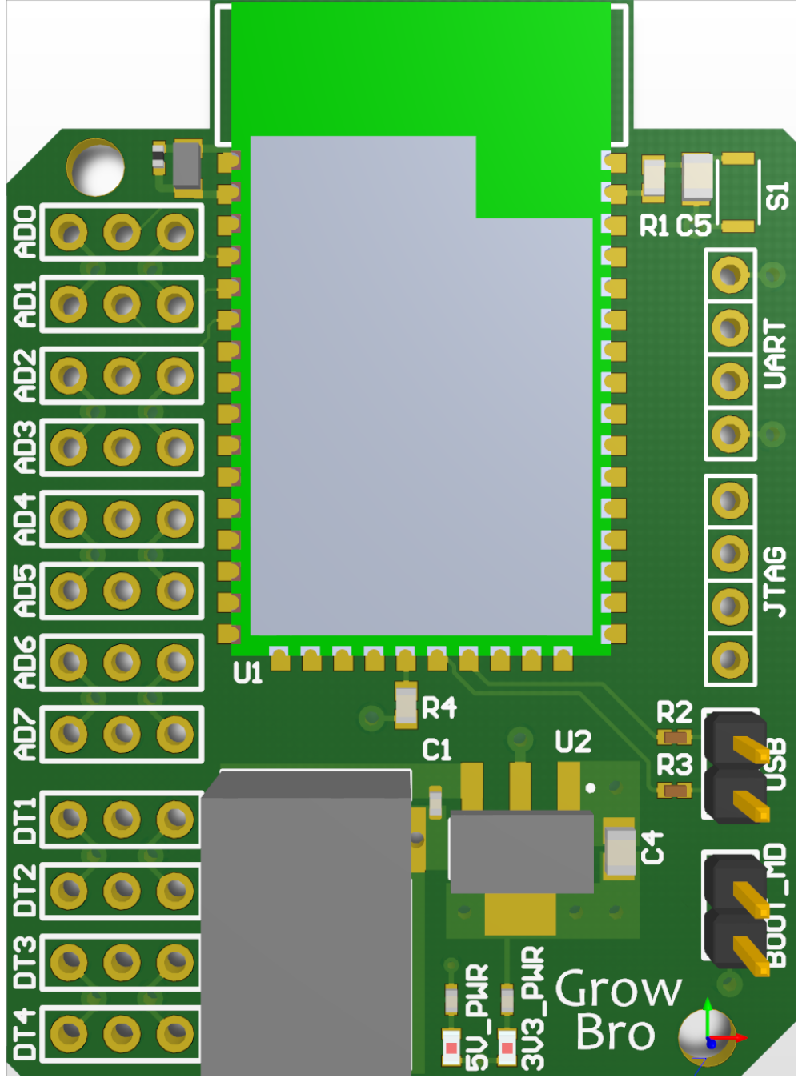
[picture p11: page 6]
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

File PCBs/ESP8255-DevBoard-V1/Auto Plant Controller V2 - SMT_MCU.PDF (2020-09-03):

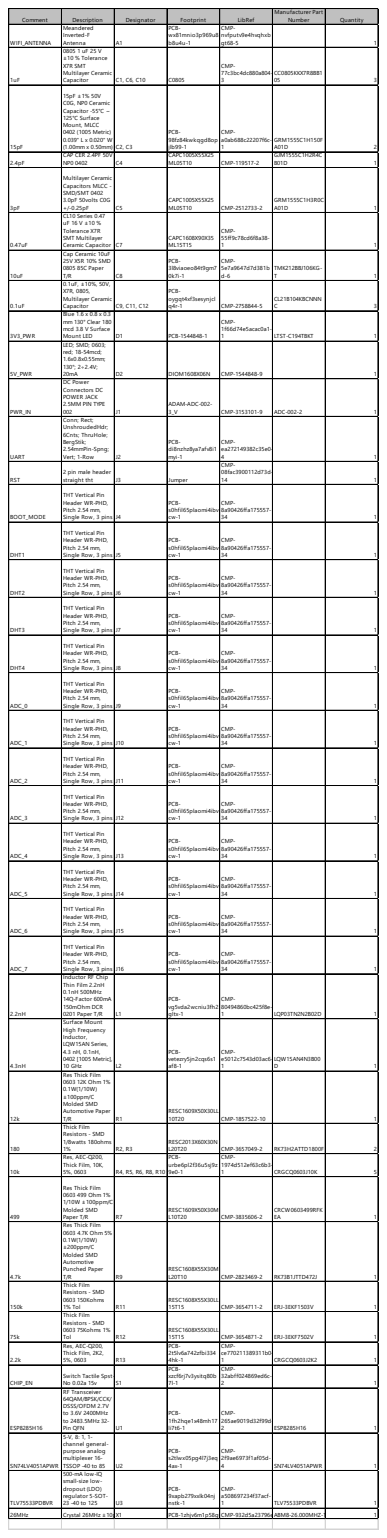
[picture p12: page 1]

WIFI_ANTENNA | Meandered Inverted-F Antenna | A1 | PCB-wx81mnio3p969u8 b8u4u-1 | CMP-nvfputv9e4hvqhxb gt68-5 | | | 1

Comment | Description | Designator | Footprint | LibRef | Manufacturer Part Number | Quantity

1uF | 0805 1 uF 25 V ±10 % Tolerance X7R SMT Multilayer Ceramic Capacitor | C1, C6, C10 | C0805 | CMP-77c3bc4dc880a804- | CC0805KKX7R8BB1 05 | | 3

15pF | 15pF ±1% 50V C0G, NP0 Ceramic Capacitor -55°C ~ 125°C Surface Mount, MLCC 0402 (1005 Metric) 0.039" L x 0.020" W (1.00mm x 0.50mm) | C2, C3 | PCB-98fz84kwkqgd8op jlb99-1 | CMP-a0ab688c22207f6c-1 | GRM1555C1H150F A01D | | 2

2.4pF | CAP CER 2.4PF 50V NP0 0402 | C4 | CAPC1005X55X25 ML05T10 | CMP-119517-2 | GJM1555C1H2R4C B01D | | 1

3pF | Multilayer Ceramic Capacitors MLCC -SMD/SMT 0402 3.0pF 50volts C0G +/-0.25pF | C5 | CAPC1005X55X25 ML05T10 | CMP-2512733-2 | GRM1555C1H3R0C A01D | | 1

0.47uF | CL10 Series 0.47 uF 16 V ±10 % Tolerance X7R SMT Multilayer Ceramic Capacitor | C7 | CAPC1608X90X35 ML15T15 | CMP-55ff9c78cd6f8a38-1 | | | 1

10uF | Cap Ceramic 10uF 25V X5R 10% SMD 0805 85C Paper T/R | C8 | PCB-3l8viaoeo84t9gm7 0k7i-1 | CMP-5e7a9647d7d381b d-6 | TMK212BBJ106KG-T | | 1

0.1uF | 0.1uF, ±10%, 50V, X7R, 0805, Multilayer Ceramic Capacitor | C9, C11, C12 | PCB-oygqt4xf3sesynjcl q4r-1 | CMP-2758844-5 | CL21B104KBCNNN C | | 3

3V3_PWR | Blue 1.6 x 0.8 x 0.3 mm 130° Clear 180 mcd 3.8 V Surface Mount LED | D1 | PCB-1544848-1 | CMP-1f66d74e5acac0a1-1 | LTST-C194TBKT | | 1

5V_PWR | LED; SMD; 0603; red; 18-54mcd; 1.6x0.8x0.55mm; 130°; 2÷2.4V; 20mA | D2 | DIOM1608X06N | CMP-1544848-9 | | | 1

PWR_IN | DC Power Connectors DC POWER JACK 2.5MM PIN TYPE 002 | J1 | ADAM-ADC-002-3_V | CMP-3153101-9 | ADC-002-2 | | 1

UART | Conn; Rect; UnshroudedHdr; 6Cnts; ThruHole; BergStik; 2.54mmPin-Spng; Vert; 1-Row | J2 | PCB-di8nzhz8ya7afv8i1 myi-1 | CMP-ea272149382c35e0-4 | | | 1

RST | 2 pin male header straight tht | J3 | Jumper | CMP-08fac3900112d73d-14 | | | 1

BOOT_MODE | THT Vertical Pin Header WR-PHD, Pitch 2.54 mm, Single Row, 3 pins | J4 | PCB-s0hfil65plaomi4ibv cw-1 | CMP-8a90426ffa175557-34 | | | 1

DHT1 | THT Vertical Pin Header WR-PHD, Pitch 2.54 mm, Single Row, 3 pins | J5 | PCB-s0hfil65plaomi4ibv cw-1 | CMP-8a90426ffa175557-34 | | | 1

DHT2 | THT Vertical Pin Header WR-PHD, Pitch 2.54 mm, Single Row, 3 pins | J6 | PCB-s0hfil65plaomi4ibv cw-1 | CMP-8a90426ffa175557-34 | | | 1

DHT3 | THT Vertical Pin Header WR-PHD, Pitch 2.54 mm, Single Row, 3 pins | J7 | PCB-s0hfil65plaomi4ibv cw-1 | CMP-8a90426ffa175557-34 | | | 1

DHT4 | THT Vertical Pin Header WR-PHD, Pitch 2.54 mm, Single Row, 3 pins | J8 | PCB-s0hfil65plaomi4ibv cw-1 | CMP-8a90426ffa175557-34 | | | 1

ADC_0 | THT Vertical Pin Header WR-PHD, Pitch 2.54 mm, Single Row, 3 pins | J9 | PCB-s0hfil65plaomi4ibv cw-1 | CMP-8a90426ffa175557-34 | | | 1

ADC_1 | THT Vertical Pin Header WR-PHD, Pitch 2.54 mm, Single Row, 3 pins | J10 | PCB-s0hfil65plaomi4ibv cw-1 | CMP-8a90426ffa175557-34 | | | 1

ADC_2 | THT Vertical Pin Header WR-PHD, Pitch 2.54 mm, Single Row, 3 pins | J11 | PCB-s0hfil65plaomi4ibv cw-1 | CMP-8a90426ffa175557-34 | | | 1

ADC_3 | THT Vertical Pin Header WR-PHD, Pitch 2.54 mm, Single Row, 3 pins | J12 | PCB-s0hfil65plaomi4ibv cw-1 | CMP-8a90426ffa175557-34 | | | 1

ADC_4 | THT Vertical Pin Header WR-PHD, Pitch 2.54 mm, Single Row, 3 pins | J13 | PCB-s0hfil65plaomi4ibv cw-1 | CMP-8a90426ffa175557-34 | | | 1

ADC_5 | THT Vertical Pin Header WR-PHD, Pitch 2.54 mm, Single Row, 3 pins | J14 | PCB-s0hfil65plaomi4ibv cw-1 | CMP-8a90426ffa175557-34 | | | 1

ADC_6 | THT Vertical Pin Header WR-PHD, Pitch 2.54 mm, Single Row, 3 pins | J15 | PCB-s0hfil65plaomi4ibv cw-1 | CMP-8a90426ffa175557-34 | | | 1

ADC_7 | THT Vertical Pin Header WR-PHD, Pitch 2.54 mm, Single Row, 3 pins | J16 | PCB-s0hfil65plaomi4ibv cw-1 | CMP-8a90426ffa175557-34 | | | 1

2.2nH | Inductor RF Chip Thin Film 2.2nH 0.1nH 500MHz 14Q-Factor 600mA 150mOhm DCR 0201 Paper T/R | L1 | PCB-vg5vda2wcniu3fh2 gltx-1 | CMP-80494860bc425f8e-1 | LQP03TN2N2B02D | | 1
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

ATA_1; 23 GPIO5; VDDP; TCK 12; MTDO 13; GPIO2 14; GPIO0 15; GPIO4 16


Weak pull down to keep low/disabled, drive high to enable


Program via UART using FTDI-USB IC


Date:; Sheet of; File:; WifiAntenna.SchDoc; Drawn By:




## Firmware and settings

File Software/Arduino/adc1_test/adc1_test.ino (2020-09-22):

//ESP32-S2 ADC CH0-8 test sketch
//Created: 9/21/2020
//Pins: 
//    IO1 4 I/O/T RTC_GPIO1, GPIO1, TOUCH1, ADC1_CH0
//    IO2 5 I/O/T RTC_GPIO2, GPIO2, TOUCH2, ADC1_CH1
//    IO3 6 I/O/T RTC_GPIO3, GPIO3, TOUCH3, ADC1_CH2
//    IO4 7 I/O/T RTC_GPIO4, GPIO4, TOUCH4, ADC1_CH3
//    IO5 8 I/O/T RTC_GPIO5, GPIO5, TOUCH5, ADC1_CH4
//    IO6 9 I/O/T RTC_GPIO6, GPIO6, TOUCH6, ADC1_CH5
//    IO7 10 I/O/T RTC_GPIO7, GPIO7, TOUCH7, ADC1_CH6
//    IO8 11 I/O/T RTC_GPIO8, GPIO8, TOUCH8, ADC1_CH7
//
//Attenuation must be set to 11dB to read up to 3.9V! All other attenuation settings are too small
//Test only uses RTC mode, DMA mode beyond our requirements

#include "driver/adc.h"
#include "esp_adc_cal.h"

static esp_adc_cal_characteristics_t *adc_chars;
static const adc_unit_t unit = ADC_UNIT_1;

#define DEFAULT_VREF    1100        //Use adc2_vref_to_gpio() to obtain a better estimate
#define NO_OF_SAMPLES 64 //Multisampling
#define atten ADC_ATTEN_DB_11
//Options: ADC_ATTEN_DB_0, ADC_ATTEN_DB_2.5, ADC_ATTEN_DB_6, ADC_ATTEN_DB_11

#define width ADC_WIDTH_BIT_13
//Options: ADC_WIDTH_BIT_9, ADC_WIDTH_BIT_10, ADC_WIDTH_BIT_11, ADC_WIDTH_BIT_12, ADC_WIDTH_BIT_13, ADC_WIDTH_BIT_MAX

void configADC(){
//Set ADC1 resolution to 13-bits, Set ADC1 attenuation to 11dB on all 8 channels, Characterize ADC
    
    esp_err_t width_status = adc1_config_width(width);
    if ( width_status == ESP_OK ) {
      Serial.println("ADC width set!");
    }else{
      Serial.println("Failed to set ADC width!");
    }
 
    for (int channel = 0; channel < 8; channel++){ 
        esp_err_t atten_status = adc1_config_channel_atten((adc1_channel_t)channel,atten);
          if ( atten_status == ESP_OK ) {
            Serial.print("ADC CH");
            Serial.print(channel);
            Serial.println(" attenuation set!");
         }else{
            Serial.print("Failed to set ADC CH");
            Serial.print(channel);
            Serial.println(" attenuation!");
          }
    }
    
    //Characterize ADC
  adc_chars = (esp_adc_cal_characteristics_t *)calloc(1, sizeof(esp_adc_cal_characteristics_t));
  esp_adc_cal_value_t val_type = esp_adc_cal_characterize(unit, atten, width, DEFAULT_VREF, adc_chars);

}

void readADC(){

    uint32_t adc_reading = 0;
    uint32_t voltage = 0 ;
    
    for (int channel = 0; channel < 8; channel++){ 
      for (int i = 0; i < NO_OF_SAMPLES; i++) { //Gather 64 samples for each channel then average
        adc_reading += adc1_get_raw((adc1_channel_t)channel);
      }
      adc_reading /= NO_OF_SAMPLES;
      
      voltage = esp_adc_cal_raw_to_voltage(adc_reading, adc_chars);
      Serial.print("ADC Channel ");
      Serial.print(channel);
      Serial.print(":  Voltage: ");
      Serial.print(voltage);
      Serial.print(" mV  Raw: ");
      Serial.println(adc_reading);

      adc_reading = 0;
      voltage = 0;
    }

    delay(5000);
    Serial.println("");
}

void setup() {
  // put your setup code here, to run once:
  Serial.begin(115200);

  if (esp_adc_cal_check_efuse(ESP_ADC_CAL_VAL_EFUSE_TP) == ESP_OK) {
    printf("eFuse Two Point: Supported\n");
  } else {
    printf("Cannot retrieve eFuse Two Point calibration values. Default calibration values will be used.\n");
  }
  configADC();

}

void loop() {
  readADC();
}
